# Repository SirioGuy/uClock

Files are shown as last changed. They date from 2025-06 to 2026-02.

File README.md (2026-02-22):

# μClock

**μClock** is a sleek, ultra-precise handheld digital clock — built for makers, engineers, and anyone who values accuracy, simplicity, and reliability.

Powered by the **ESP32-C3**, μClock includes an ultra-precise real-time clock that automatically corrects itself via **NTP servers**, ensuring it's always perfectly on time.

## Features

- ESP32-C3 + 1.3" OLED
- Ultra-low power design
- High-precision clock (±1 PPM)
- NTP sync over Wi-Fi
- Time zone selection
- Open source and customizable

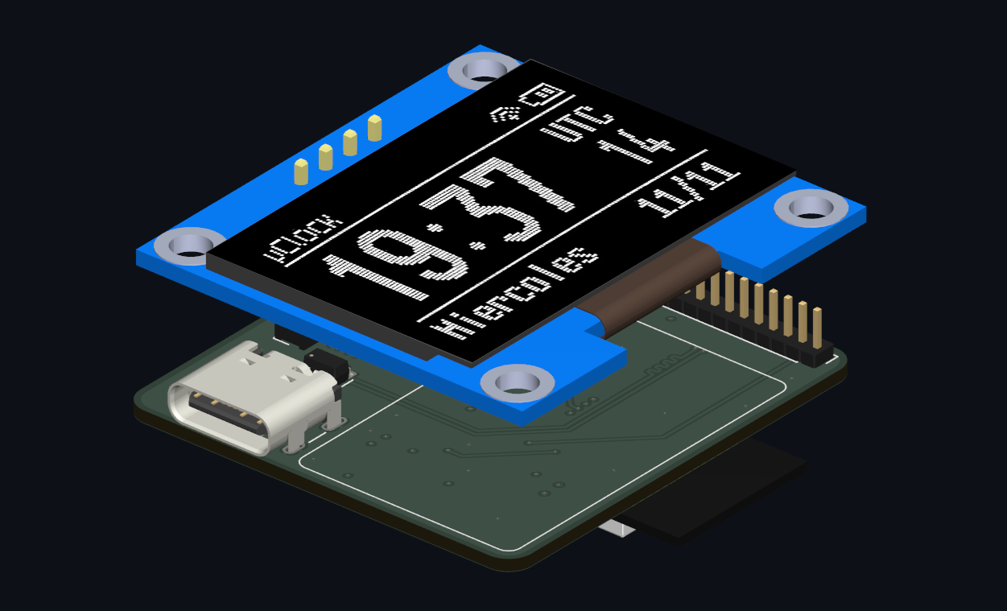
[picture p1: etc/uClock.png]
μClock Banner


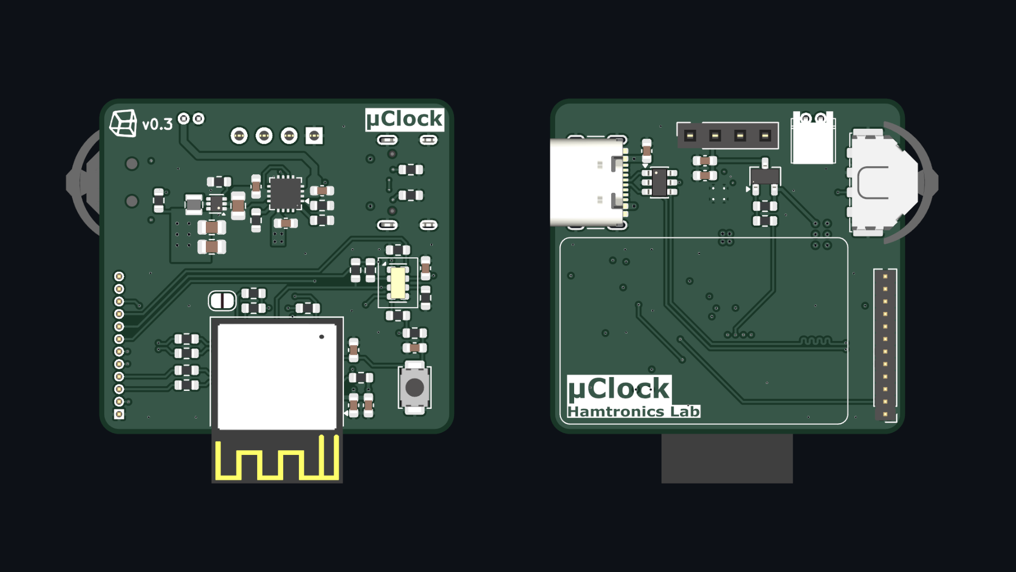
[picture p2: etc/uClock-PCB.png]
μClock PCB


> Work in progress — Hardware revision under validation.

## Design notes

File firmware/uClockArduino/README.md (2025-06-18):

# WARNING

This code it's for Arduino testing. ESP version currently on developing. **Take care**.

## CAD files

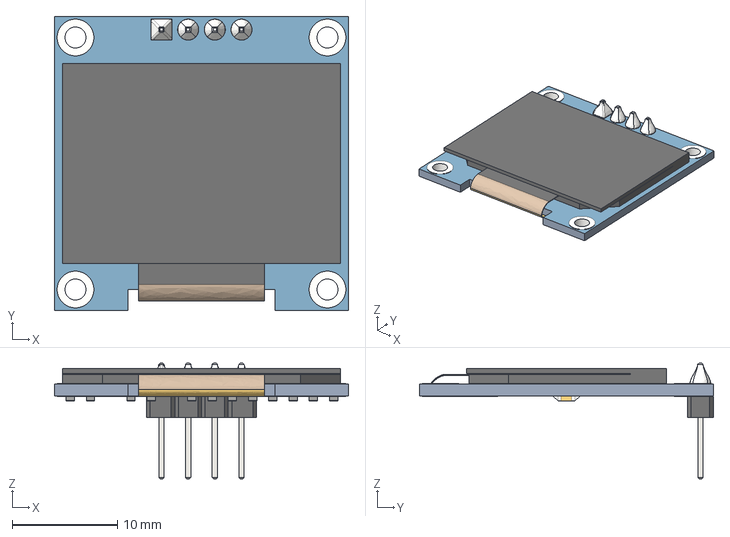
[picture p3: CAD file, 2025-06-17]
hardware/etc/3d models/0.96 OLED v3.step
28.0 x 28.0 x 11.0 mm

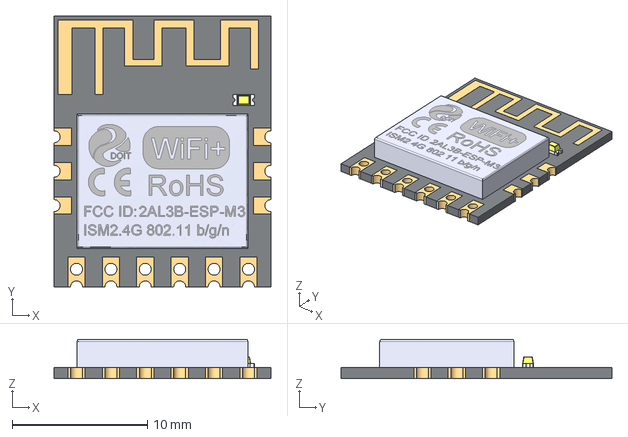
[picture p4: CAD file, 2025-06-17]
hardware/etc/3d models/ESP-M3.stp
16.0 x 20.0 x 2.91 mm

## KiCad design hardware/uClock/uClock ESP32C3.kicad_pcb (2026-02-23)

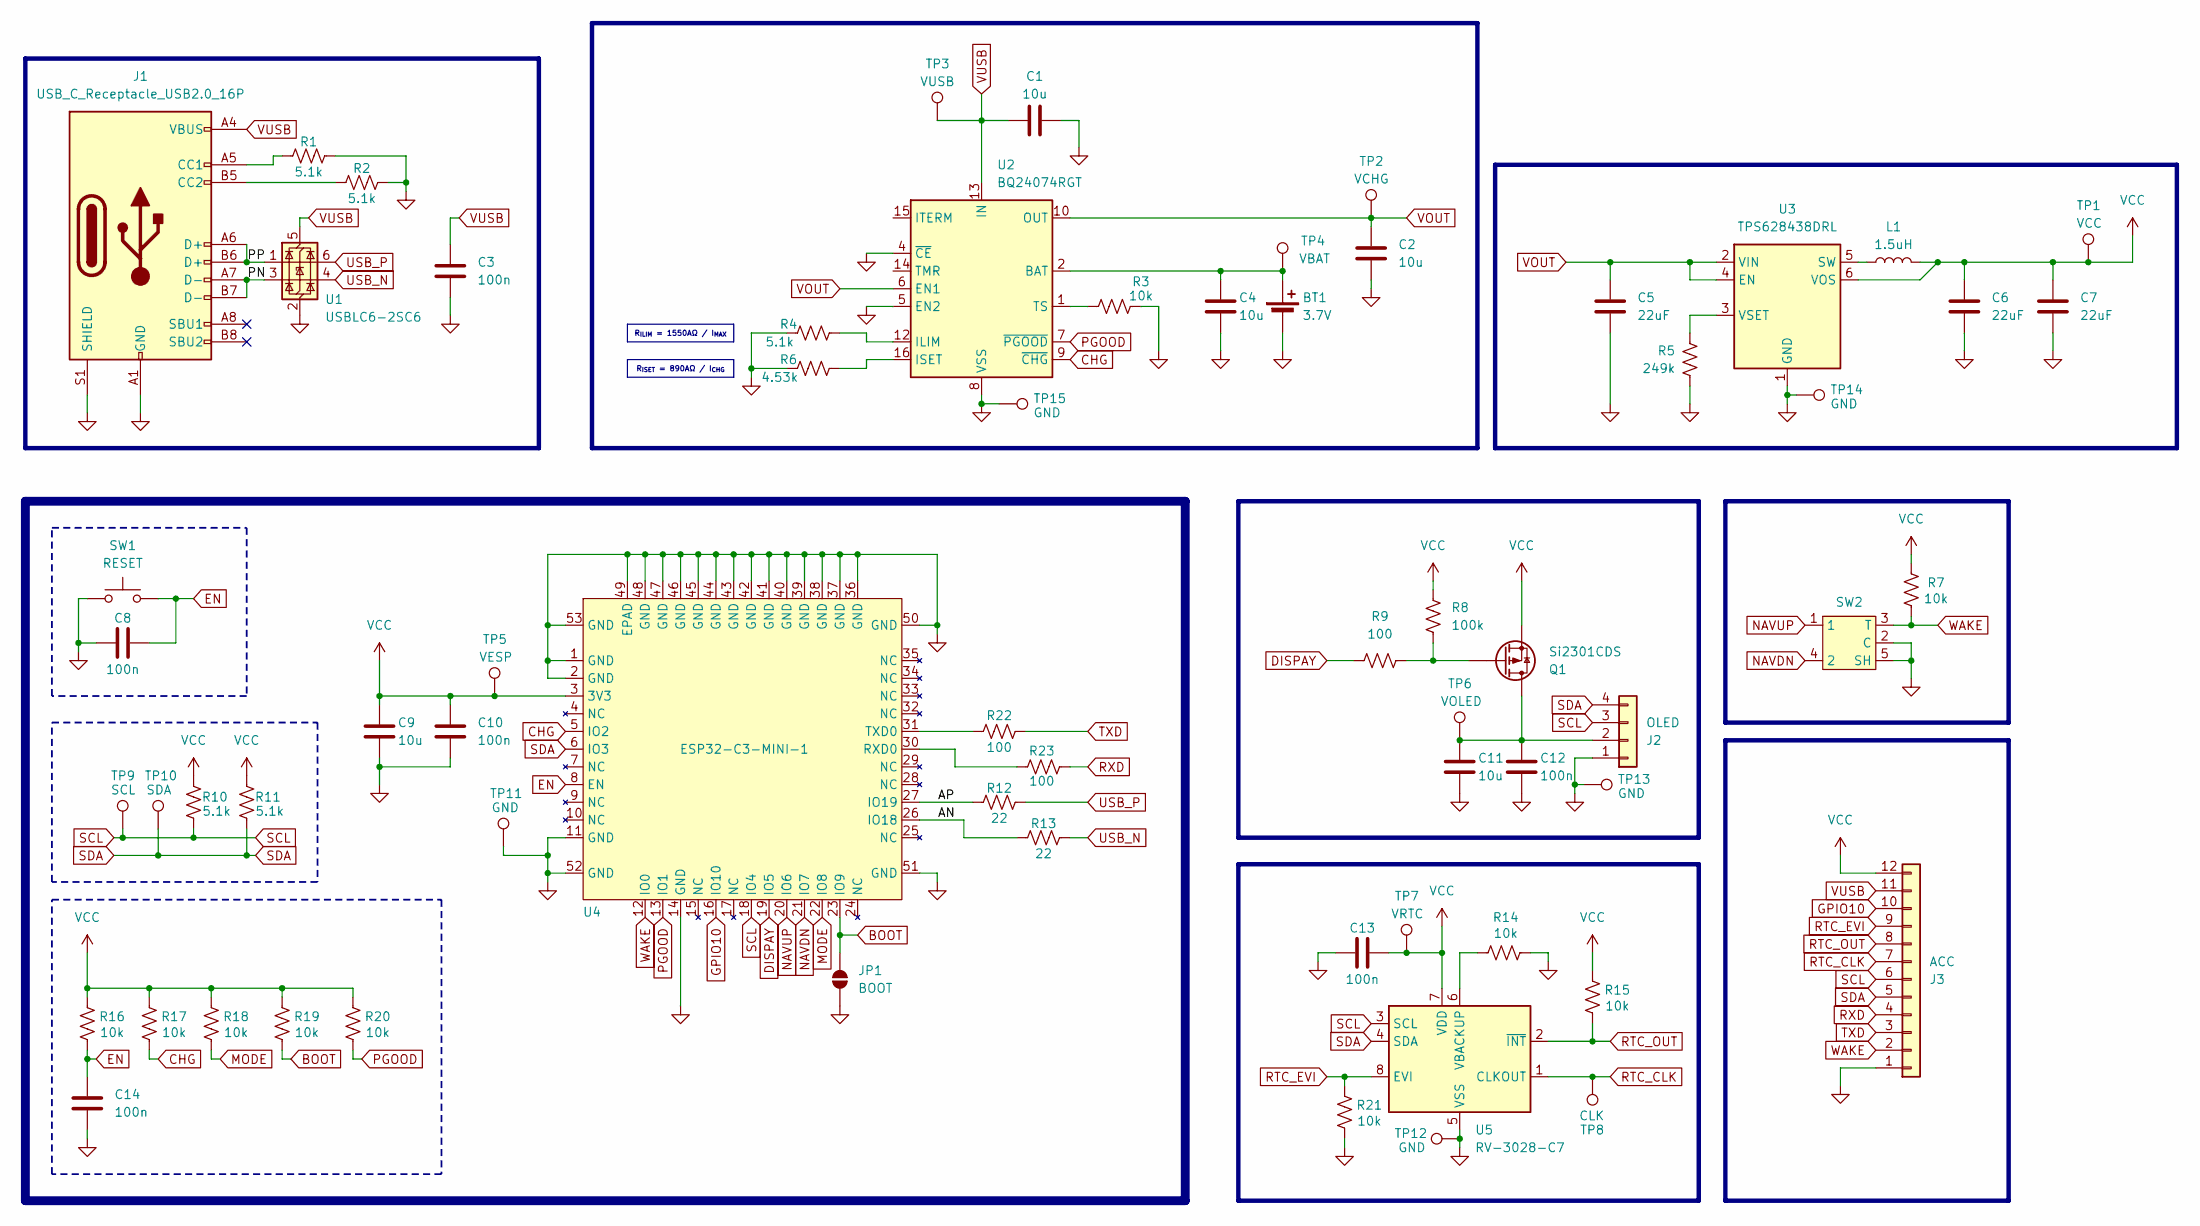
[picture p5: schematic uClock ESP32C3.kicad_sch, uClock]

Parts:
BT1: 3.7V; JST-ZH-02AW-P=1.5-H3.6; LCSC C722934
C1, C2, C4, C9, C11: 10u; C_0603_1608Metric; LCSC C19702
C3, C8, C10, C12, C13, C14: 100n; C_0603_1608Metric; LCSC C14663
C5, C6, C7: 22uF; C_0805_2012Metric; LCSC C907991
J1: USB_C_Receptacle_USB2.0_16P; USB_C_Receptacle_GCT_USB4105-xx-A_16P_TopMnt_Horizontal; LCSC C2765186
J2: OLED; PinSocket_1x04_P2.54mm_Vertical
J3: ACC; PinHeader_1x12_P1.27mm_Vertical
JP1: BOOT; SolderJumper-2_P1.3mm_Open_RoundedPad1.0x1.5mm
L1: 1.5uH; L_0806; LCSC C3020027
Q1: Si2301CDS; TSOT-23; LCSC C10487
R1, R2, R4, R10, R11: 5.1k; R_0603_1608Metric; LCSC C23186
R3, R7, R14, R15, R16, R17, R18, R19, R20, R21: 10k; R_0603_1608Metric; LCSC C25804
R5: 249k; R_0603_1608Metric; LCSC C22918
R6: 4.53k; R_0603_1608Metric; LCSC C25971
R8: 100k; R_0603_1608Metric; LCSC C25803
R9, R22, R23: 100; R_0603_1608Metric; LCSC C22775
R12, R13: 22; R_0603_1608Metric; LCSC C23345
SW1: RESET; SW_SPST_TS-1088-xR020; LCSC C720477
SW2: K1-1511SA-01; LCSC C145907
TP1: VCC; TestPoint_Pad_D1.0mm
TP2: VCHG; TestPoint_Pad_D1.0mm
TP3: VUSB; TestPoint_Pad_D1.0mm
TP4: VBAT; TestPoint_Pad_D1.0mm
TP5: VESP; TestPoint_Pad_D1.0mm
TP6: VOLED; TestPoint_Pad_D1.0mm
TP7: VRTC; TestPoint_Pad_D1.0mm
TP8: CLK; TestPoint_Pad_D1.0mm
TP9: SCL; TestPoint_Pad_D1.0mm
TP10: SDA; TestPoint_Pad_D1.0mm
TP11, TP12, TP13, TP14, TP15: GND; TestPoint_Pad_D1.0mm
U1: USBLC6-2SC6; SOT-23-6; LCSC C7519
U2: BQ24074RGT; VQFN-16-1EP_3x3mm_P0.5mm_EP1.6x1.6mm_ThermalVias; LCSC C54313
U3: TPS628438DRL; SOT-563; LCSC C38060243
U4: ESP32-C3-MINI-1; LCSC C2934569
U5: RV-3028-C7; MicroCrystal_C7_SON-8_1.5x3.2mm_P0.9mm; LCSC C3019759

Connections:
/AN: R13.1, U4.26 (IO18)
/AP: R12.1, U4.27 (IO19)
/PN: J1.A7 (D-), J1.B7 (D-), U1.3 (I/O2)
/PP: J1.A6 (D+), J1.B6 (D+), U1.1 (I/O1)
BOOT: JP1.2 (B), R19.2, U4.23 (IO9)
CHG: R17.2, U2.9 (~CHG), U4.5 (IO2)
DISPAY: R9.1, U4.19 (IO5)
EN: C8.2, C14.1, R16.2, SW1.2, U4.8 (EN)
GND: BT1.2 (-), C1.2, C2.2, C3.2, C4.2, C5.2, C6.2, C7.2, C8.1, C9.2, C10.2, C11.2, C12.2, C13.1, C14.2, J1.A1 (GND), J1.A12 (GND), J1.B1 (GND), J1.B12 (GND), J1.S1 (SHIELD), J2.1, J3.1, JP1.1 (A), R1.2, R2.2, R3.2, R4.1, R5.2, R6.1, R14.2, R21.2, SW1.1, SW2.2 (C), SW2.5 (SH), TP11.1, TP12.1, TP13.1, TP14.1, TP15.1, U1.2 (GND), U2.4 (~CE), U2.5 (EN2), U2.8 (VSS), U2.17 (VSS), U3.1 (GND), U4.1 (GND), U4.2 (GND), U4.11 (GND), U4.14 (GND), U4.36 (GND), U4.37 (GND), U4.38 (GND), U4.39 (GND), U4.40 (GND), U4.41 (GND), U4.42 (GND), U4.43 (GND), U4.44 (GND), U4.45 (GND), U4.46 (GND), U4.47 (GND), U4.48 (GND), U4.49 (EPAD), U4.50 (GND), U4.51 (GND), U4.52 (GND), U4.53 (GND), U5.5 (VSS)
GPIO10: J3.10, U4.16 (IO10)
MODE: R18.2, U4.22 (IO8)
NAVDN: SW2.4 (2), U4.21 (IO7)
NAVUP: SW2.1, U4.20 (IO6)
unnamed: BT1.1 (+), C4.1, TP4.1, U2.2 (BAT), U2.3 (BAT)
unnamed: J1.A5 (CC1), R1.1
unnamed: J1.B5 (CC2), R2.1
unnamed: C11.1, C12.1, J2.2, Q1.3 (D), TP6.1
unnamed: Q1.1 (G), R8.2, R9.2
unnamed: R4.2, U2.12 (ILIM)
unnamed: R6.2, U2.16 (ISET)
unnamed: R3.1, U2.1 (TS)
unnamed: L1.1, U3.5 (SW)
unnamed: R5.1, U3.3 (VSET)
unnamed: R23.1, U4.30 (RXD0)
unnamed: R22.1, U4.31 (TXD0)
unnamed: R14.1, U5.6 (VBACKUP)
PGOOD: R20.2, U2.7 (~PGOOD), U4.13 (IO1)
RTC_CLK: J3.7, TP8.1, U5.1 (CLKOUT)
RTC_EVI: J3.9, R21.1, U5.8 (EVI)
RTC_OUT: J3.8, R15.2, U5.2 (~INT)
RXD: J3.4, R23.2
SCL: J2.3, J3.6, R10.1, TP9.1, U4.18 (IO4), U5.3 (SCL)
SDA: J2.4, J3.5, R11.1, TP10.1, U4.6 (IO3), U5.4 (SDA)
TXD: J3.3, R22.2
USB_N: R13.2, U1.4 (I/O2)
USB_P: R12.2, U1.6 (I/O1)
VCC: C6.1, C7.1, C9.1, C10.1, C13.2, J3.12, L1.2, Q1.2 (S), R7.1, R8.1, R10.2, R11.2, R15.1, R16.1, R17.1, R18.1, R19.1, R20.1, TP1.1, TP5.1, TP7.1, U3.6 (VOS), U4.3 (3V3), U5.7 (VDD)
VOUT: C2.1, C5.1, TP2.1, U2.6 (EN1), U2.10 (OUT), U2.11 (OUT), U3.2 (VIN), U3.4 (EN)
VUSB: C1.1, C3.1, J1.A4 (VBUS), J1.A9 (VBUS), J1.B4 (VBUS), J1.B9 (VBUS), J3.11, TP3.1, U1.5 (VBUS), U2.13 (IN)
WAKE: J3.2, R7.2, SW2.3 (T), U4.12 (IO0)

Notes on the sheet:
R_{ILIM} = 1550AΩ / I_{MAX}
R_{ISET} = 890AΩ / I_{CHG}

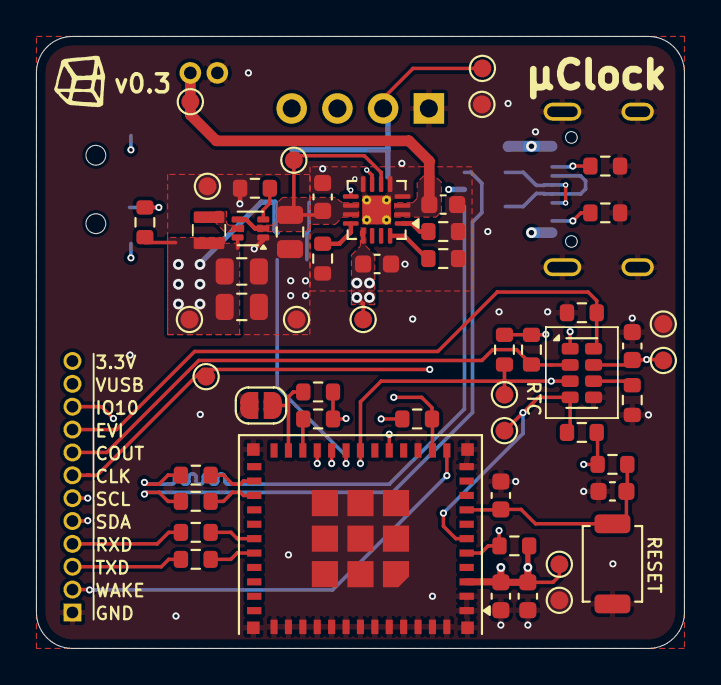
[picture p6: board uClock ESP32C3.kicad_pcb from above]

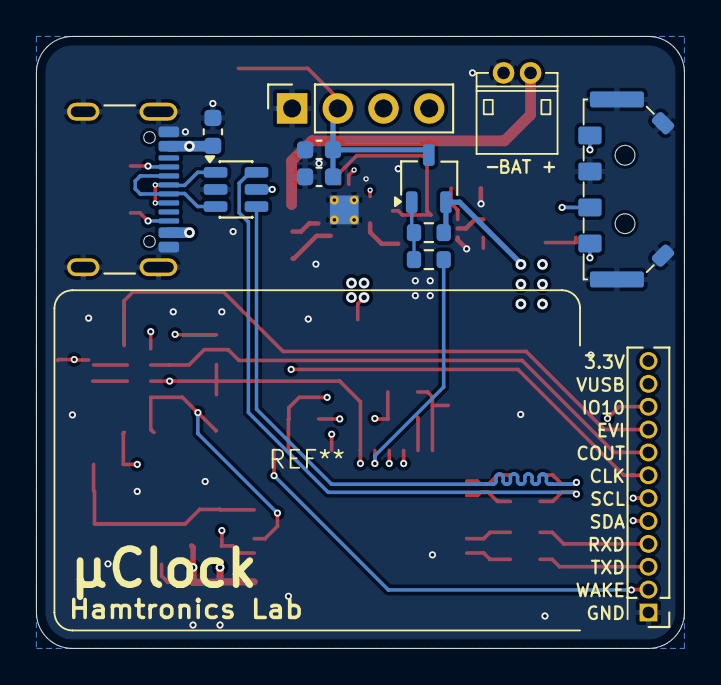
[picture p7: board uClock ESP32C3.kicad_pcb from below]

Board: 4 copper layers, 36.0 x 34.0 mm, 66 parts (12 on the bottom side), 40 nets.

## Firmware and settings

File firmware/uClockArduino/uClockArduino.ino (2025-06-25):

#include "display.h"
#include "ClickButton.h"

U8G2_SSD1306_128X64_NONAME_1_HW_I2C oled(U8G2_R0, U8X8_PIN_NONE);

const int buttonPin = 2;

// ~ VARIABLES ~

unsigned long now;
unsigned long lastPulse;
unsigned long lastClock;

bool displayOn = 1;

int hour = 19;
int minute = 37;
int second = 10;

char secondChar[3];
char clockChar[9];

char timezoneChar[4];

float batteryLevel = 90;

int displayTimeout = 5000;


// ~ Inicialización ~

ClickButton button(buttonPin, LOW, CLICKBTN_PULLUP);

void setup() {
  Serial.begin(115200);

  oled.begin();

  button.longClickTime = 300;
  button.debounceTime = 10;
}


// ~ Main Loop ~

void loop() {

  now = millis();
  button.Update();

  if(now - lastClock >= 1000){
    runClock();
    batteryLevel -= 2;
    lastClock = now;
  }
  if(button.clicks == 1 && displayOn == false) {
    displayOn = true;
    lastPulse = now;
  }

  if(displayOn){
    display();
  }

  if (now - lastPulse >= displayTimeout && displayOn == true) {
    oled.setPowerSave(1);
    displayOn = false;
  }






  /*if(now - lastClock >= 1000){
    runClock();
    batteryLevel -= 5;
    lastClock = now;
  }

  if (button.clicks == 0) {
    lastPulse = now;
    displayOn = true;
    oled.setPowerSave(0);
  }

  // Si el display está encendido, mostrar y controlar apagado por timeout
  if (displayOn) {
    display();

    if (now - lastPulse >= displayTimeout) {
      oled.setPowerSave(1);
      displayOn = false;
    }
  }*/
}

void runClock(){
  second++;
  if(second == 60){
    second = 0;
    minute++;
  }
  if(minute == 60){
    minute = 0;
    hour++;
  }
  if(hour == 24){
    hour = 0;
  }

  sprintf(clockChar, "%02d:%02d", hour, minute);
  sprintf(secondChar, "%02d", second);
}

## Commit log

2025-06-17 3d models
    [0.96 OLED v3.step, ESP-M3.stp]
2025-06-17 Update folders
    [0.96 OLED v3.step, ESP-M3.stp, uClock.kicad_pcb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]
2025-06-17 Update kicad files
    [uClock.kicad_pcb]
2025-06-18 PCB Update - rev2
    - CH340 power corrected
    - Optimized RTC conspumtion
    - Pullup added to SW1
    [uClock.kicad_pcb, uClock.kicad_sch]
2025-06-21 Updated PCB to REV-3
    - Updated PCB traces tolerances from 0.3mm to 0.2mm
    - Optimized some traces
    [uClock.kicad_pcb]
2026-02-21 ESP32C3 Ver 0.3 Rev 1
    [JST 2pin rightangle.stp, OLED.STEP, QFN16 4x4.STEP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]
2026-02-23 Update Ver 0.3 REV 1
    [JST 2pin rightangle.stp, OLED.STEP, QFN16 4x4.STEP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]
